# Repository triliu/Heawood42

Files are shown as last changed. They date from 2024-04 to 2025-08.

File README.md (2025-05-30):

# Heawood42

The Heawood42 is a diodeless 42-key ortho-linear split keyboard that uses any pro micro microcontroller. The Heawood42 utilises a new type of circuit design stemming from graph theory and mathematical design theory. All previous diodeless keyboards work using one pin per key, such as the [sweep](https://github.com/davidphilipbarr/Sweep), which uses 17 pins to control 17 keys per side, the [sweeeeep](https://fingerpunch.xyz/product/sweeeeep/), which uses 17 pins to control 17 keys per side, the [cantor](https://github.com/diepala/cantor), which uses 18 pins to control 18 keys per side, and the [piantor](https://github.com/beekeeb/piantor), which uses 21 pins to control 21 keys per side. The first two keyboards can use any pro micro-style board (traditionally, the pro micro-style boards have 18 pins available, but one of these pins is required for communication among the halves). The third and fourth keyboard requires the use of a larger microcontroller, the BlackPills and the Raspberry Pi Pico, respectively. 

The Heawood42 is the first split diodeless keyboard requiring fewer pins than keys. Each side uses 14 pins to control 21 keys. This means that even on a typical pro micro-style board, the Heawood42 may have inter-board communication, addressable RGB lights, and an OLED screen. 

Due to its diodeless-ness, the Heawood42 is ideal in several cases, as it reduces the cost and complexity of making a custom mechanical keyboard.




## Why 'Heawood'?

Typical mechanical keyboards arrange their keys in a grid pattern. In such a grid, there are cycles of four keys. If no diodes were used and three keys of a four-key cycle were pressed, the keyboard would act like all four keys were being pressed. See https://pcbheaven.com/wikipages/How_Key_Matrices_Works/ for an explainer of this phenomenon. By adding a diode to every key, the keyboard becomes "n-key rollover", meaning that the keyboard can theoretically distinguish all combinations of keypresses. In software, however, 6-key rollover is typically used, meaning the software assumes that if more than six keys are being pressed, then keys were pressed on accident. The USB keyboard protocol is limited to a 6-key rollover. For split keyboards, a 6-key rollover on each half is excessive, as typically one finger would only press one key at a time, and even a 5-key rollover is more than is needed. 

In graph theory, it is possible to make graphs that do not contain small cycles. Each graph can be converted into a new type of key matrix, with differing characteristics. The Heawood graph is a graph that is the incidence graph of a projective plane of order 2, and has 14 vertices, 21 edges, and a girth of 6. For more details on this graph, see [House of Graphs](https://houseofgraphs.org/graphs/1154). This graph converts to a key matrix with just a 4-key rollover. However, by designing the board specifically, all problematic 5-key and 6-key sequences may be practically eliminated, yielding the Heawood42. 



This design is powered using any pro micro-style microcontroller.

## Versions
- Regular MX-hotswap version
    - 19.05 x 19.05 spacing
    - MX hot-swap style holes (requires 42 MX hot-swap sockets)
    - Per-key RGB LEDs (optional)
- Choc-hotswap version
    - 18 x 17 spacing
    - Choc hot-swap style holes (requires 42 choc hot-swap sockets)
    - Per-key RGB LEDs (optional)

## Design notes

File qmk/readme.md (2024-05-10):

# Heawood42

Explainer

* Keyboard Maintainer: [Triliu](https://github.com/triliu) 
* Hardware Supported: Heawood42 v1
* Hardware Availability: (coming)

Place these files in .../qmk_firmware/keyboards/triliu/heawood42

To compile in QMK MYSY, run command:

    qmk compile -kb triliu/heawood42/rp2040 -km default
    (coming soon) qmk compile -kb triliu/heawood42/avr -km default

Make example for this keyboard (after setting up your build environment):

    make triliu/heawood42/rp2040:default
    (coming soon) make triliu/heawood42/avr:default

Flashing example for this keyboard:

    make triliu/heawood42/rp2040:default:flash
    (coming soon) make triliu/heawood42/avr:default:flash

First time accessing the bootloader, you might have to hold the boot button and then press the reset button. 
Subsequently, enter bootloader by double-tapping reset button

See the [build environment setup](https://docs.qmk.fm/#/getting_started_build_tools) and the [make instructions](https://docs.qmk.fm/#/getting_started_make_guide) for more information. Brand new to QMK? Start with our [Complete Newbs Guide](https://docs.qmk.fm/#/newbs).

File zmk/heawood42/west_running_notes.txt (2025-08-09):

devcontainer up --workspace-folder "/home/triliu/gits/zmk"
docker ps
docker exec -w /workspaces/zmk -i d5a17f3ab6ca /bin/bash 

west build -p -d build/heawood42/left -b nice_nano_v2 -S studio-rpc-usb-uart -- -DSHIELD=heawood42_left -DCONFIG_ZMK_STUDIO=y
west build -p -d build/heawood42/right -b nice_nano_v2 -S studio-rpc-usb-uart -- -DSHIELD=heawood42_right -DCONFIG_ZMK_STUDIO=y
west build -p -d build/reset -b nice_nano_v2 -- -DSHIELD=settings_reset

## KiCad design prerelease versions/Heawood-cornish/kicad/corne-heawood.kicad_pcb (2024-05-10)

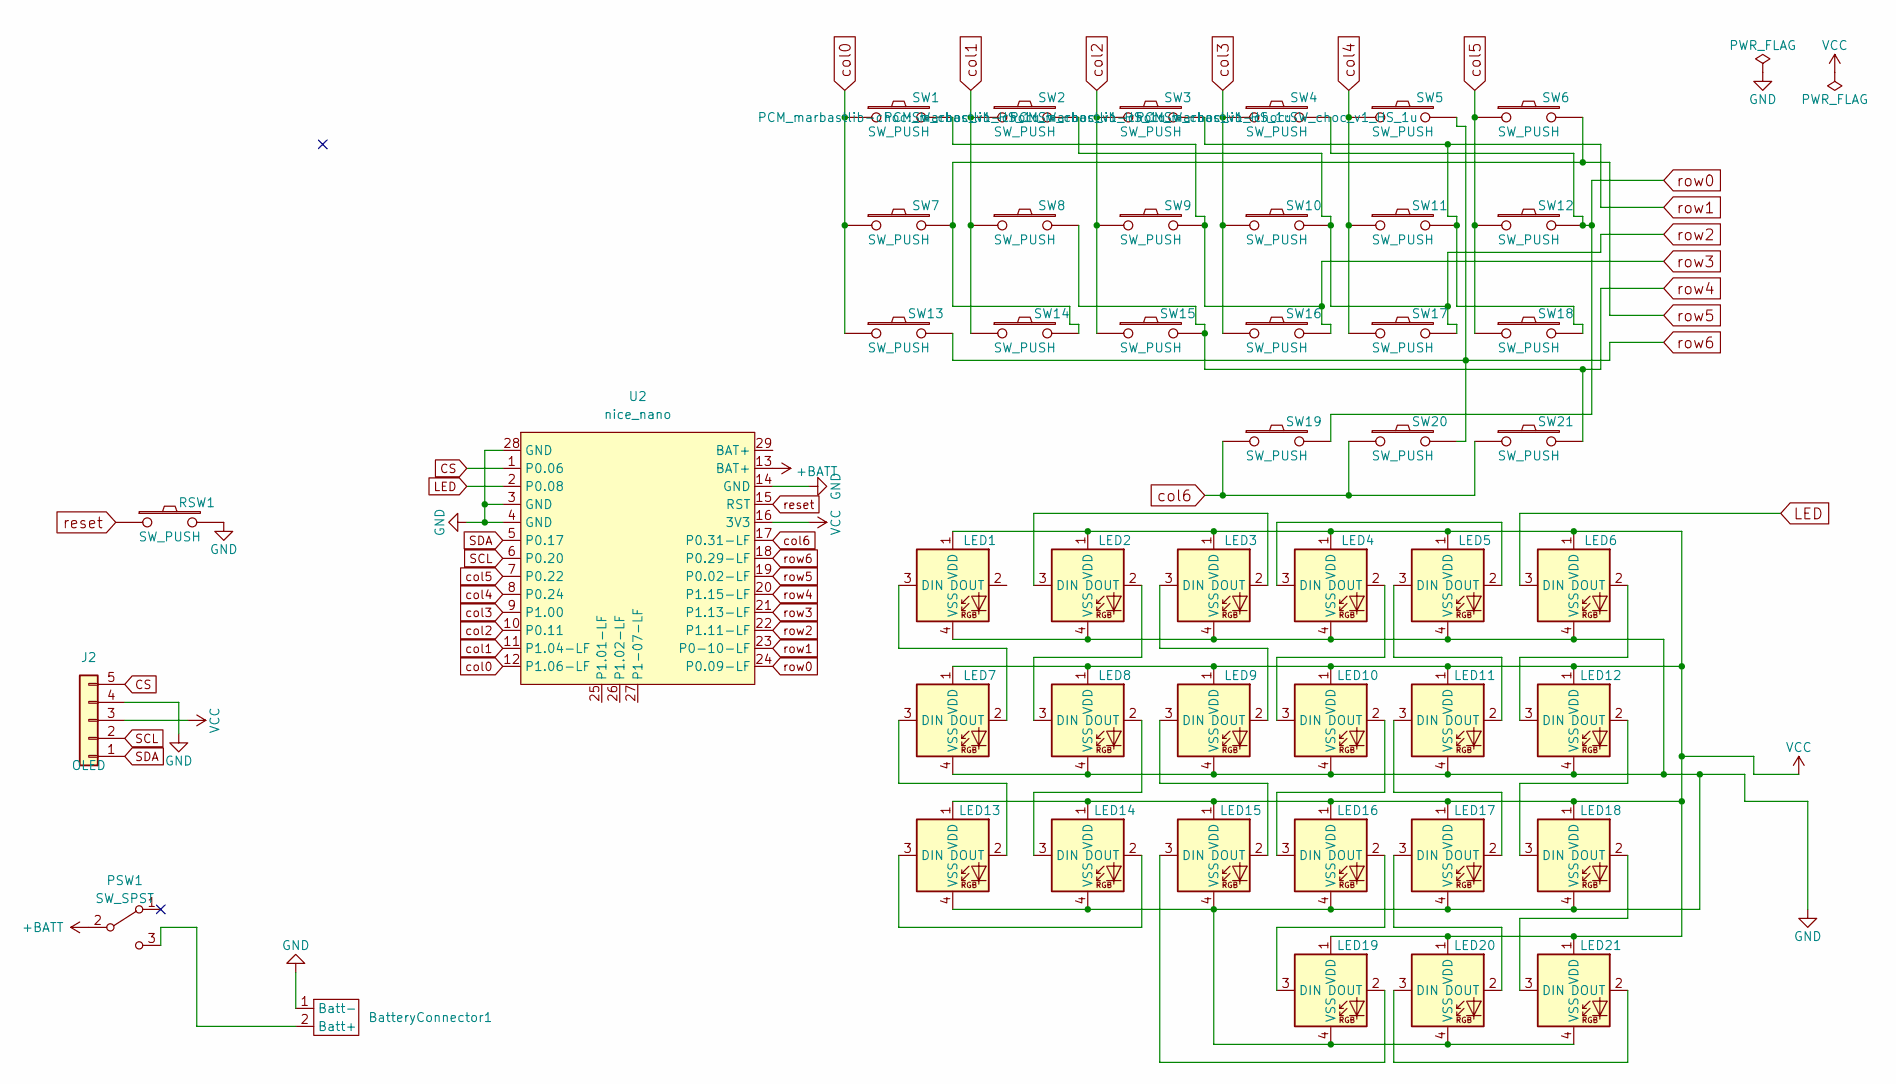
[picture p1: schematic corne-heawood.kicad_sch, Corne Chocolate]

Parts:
BatteryConnector1: 2pad_battery_input
J2: OLED; nice_view_1side
LED1, LED2, LED3, LED4, LED5, LED6, LED7, LED8, LED9, LED10, LED11, LED12, LED13, LED14, LED15, LED16, LED17, LED18, LED19, LED20, LED21: SK6812MINI-E; LED_6028R
PSW1: SW_SPST; SW_SPDT_PCM12
RSW1: SW_PUSH; ResetSW
SW1, SW2, SW3, SW4, SW5, SW6, SW7, SW8, SW9, SW10, SW11, SW12, SW13, SW14, SW15, SW16, SW17, SW18, SW19, SW20: SW_PUSH; SW_choc_v1_HS_1u
SW21: SW_PUSH; SW_choc_v1_HS_1.5u
U2: nice_nano; ProMicro_USBdn

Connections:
+BATT: PSW1.2 (B), U2.13 (BAT+)
CS: U2.1 (P0.06); also elsewhere on the board
GND: BatteryConnector1.1 (Batt-), LED1.4 (VSS), LED2.4 (VSS), LED3.4 (VSS), LED4.4 (VSS), LED5.4 (VSS), LED6.4 (VSS), LED7.4 (VSS), LED8.4 (VSS), LED9.4 (VSS), LED10.4 (VSS), LED11.4 (VSS), LED12.4 (VSS), LED13.4 (VSS), LED14.4 (VSS), LED15.4 (VSS), LED16.4 (VSS), LED17.4 (VSS), LED18.4 (VSS), LED19.4 (VSS), LED20.4 (VSS), LED21.4 (VSS), RSW1.2, U2.3 (GND), U2.4 (GND), U2.14 (GND), U2.28 (GND); also elsewhere on the board
LED: LED6.3 (DIN), U2.2 (P0.08)
unnamed 4: BatteryConnector1.2 (Batt+), PSW1.3 (C); also elsewhere on the board
unnamed: LED1.3 (DIN), LED7.2 (DOUT)
unnamed: LED2.3 (DIN), LED3.2 (DOUT)
unnamed: LED2.2 (DOUT), LED8.3 (DIN)
unnamed: LED3.3 (DIN), LED9.2 (DOUT)
unnamed: LED4.3 (DIN), LED5.2 (DOUT)
unnamed: LED4.2 (DOUT), LED10.3 (DIN)
unnamed: LED10.2 (DOUT), LED16.3 (DIN)
unnamed: LED11.3 (DIN), LED17.2 (DOUT)
unnamed: LED5.3 (DIN), LED11.2 (DOUT)
unnamed: LED6.2 (DOUT), LED12.3 (DIN)
unnamed: LED12.2 (DOUT), LED18.3 (DIN)
unnamed: LED13.3 (DIN), LED14.2 (DOUT)
unnamed: LED7.3 (DIN), LED13.2 (DOUT)
unnamed: LED8.2 (DOUT), LED14.3 (DIN)
unnamed: LED15.3 (DIN), LED19.2 (DOUT)
unnamed: LED9.3 (DIN), LED15.2 (DOUT)
unnamed: LED16.2 (DOUT), LED19.3 (DIN)
unnamed: LED17.3 (DIN), LED20.2 (DOUT)
unnamed: LED18.2 (DOUT), LED21.3 (DIN)
unnamed: LED20.3 (DIN), LED21.2 (DOUT)
SCL: U2.6 (P0.20); also elsewhere on the board
SDA: U2.5 (P0.17); also elsewhere on the board
VCC: LED1.1 (VDD), LED2.1 (VDD), LED3.1 (VDD), LED4.1 (VDD), LED5.1 (VDD), LED6.1 (VDD), LED7.1 (VDD), LED8.1 (VDD), LED9.1 (VDD), LED10.1 (VDD), LED11.1 (VDD), LED12.1 (VDD), LED13.1 (VDD), LED14.1 (VDD), LED15.1 (VDD), LED16.1 (VDD), LED17.1 (VDD), LED18.1 (VDD), LED19.1 (VDD), LED20.1 (VDD), LED21.1 (VDD), U2.16 (3V3); also elsewhere on the board
col0: SW1.1, SW7.1, SW13.1, U2.12 (P1.06-LF)
col1: SW2.1, SW8.1, SW14.1, U2.11 (P1.04-LF)
col2: SW3.1, SW9.1, SW15.1, U2.10 (P0.11)
col3: SW4.1, SW10.1, SW16.1, U2.9 (P1.00)
col4: SW5.1, SW11.1, SW17.1, U2.8 (P0.24)
col5: SW6.1, SW12.1, SW18.1, U2.7 (P0.22)
col6: SW19.1, SW20.1, SW21.1, U2.17 (P0.31-LF)
reset: RSW1.1, U2.15 (RST)
row0: SW4.2, SW12.2, SW19.2, U2.24 (P0.09-LF)
row1: SW3.2, SW11.2, SW18.2, U2.23 (P0-10-LF)
row2: SW2.2, SW10.2, SW17.2, U2.22 (P1.11-LF)
row3: SW1.2, SW9.2, SW16.2, U2.21 (P1.13-LF)
row4: SW8.2, SW15.2, SW21.2, U2.20 (P1.15-LF)
row5: SW6.2, SW7.2, SW14.2, U2.19 (P0.02-LF)
row6: SW5.2, SW13.2, SW20.2, U2.18 (P0.29-LF)

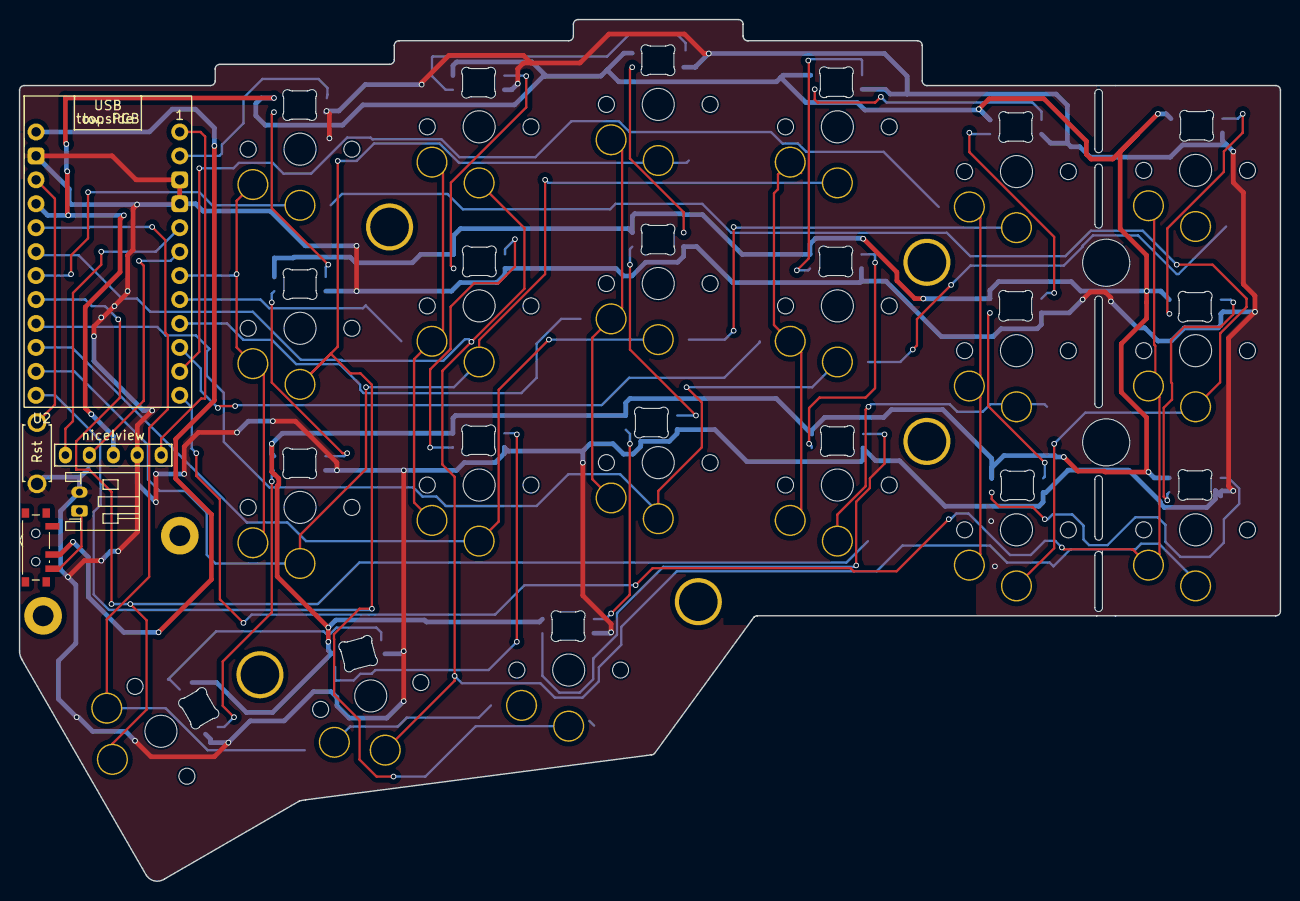
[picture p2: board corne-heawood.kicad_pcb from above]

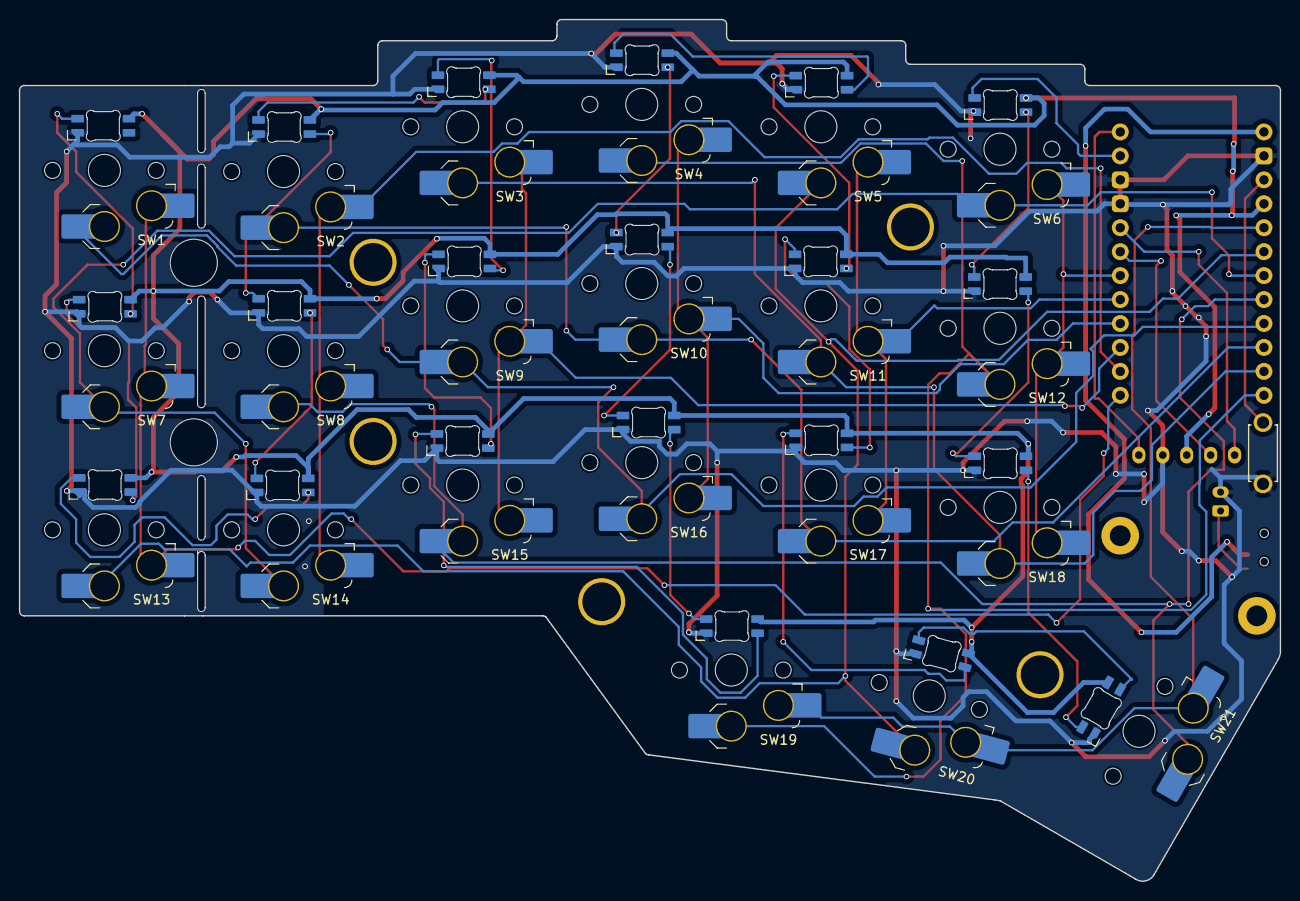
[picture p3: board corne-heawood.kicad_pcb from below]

Board: 2 copper layers, 133.8 x 91.4 mm, 47 parts (43 on the bottom side), 43 nets.

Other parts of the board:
BATJ2: Conn_01x02_Female; JST_PH_S2B-PH-K_1x02_P2.00mm_Horizontal
J1: OLED; nice_view_1side

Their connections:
CS: J1.5; also elsewhere on the board
GND: BATJ2.2, J1.4; also elsewhere on the board
unnamed 4: BATJ2.1; also elsewhere on the board
SCL: J1.2; also elsewhere on the board
SDA: J1.1; also elsewhere on the board
VCC: J1.3; also elsewhere on the board

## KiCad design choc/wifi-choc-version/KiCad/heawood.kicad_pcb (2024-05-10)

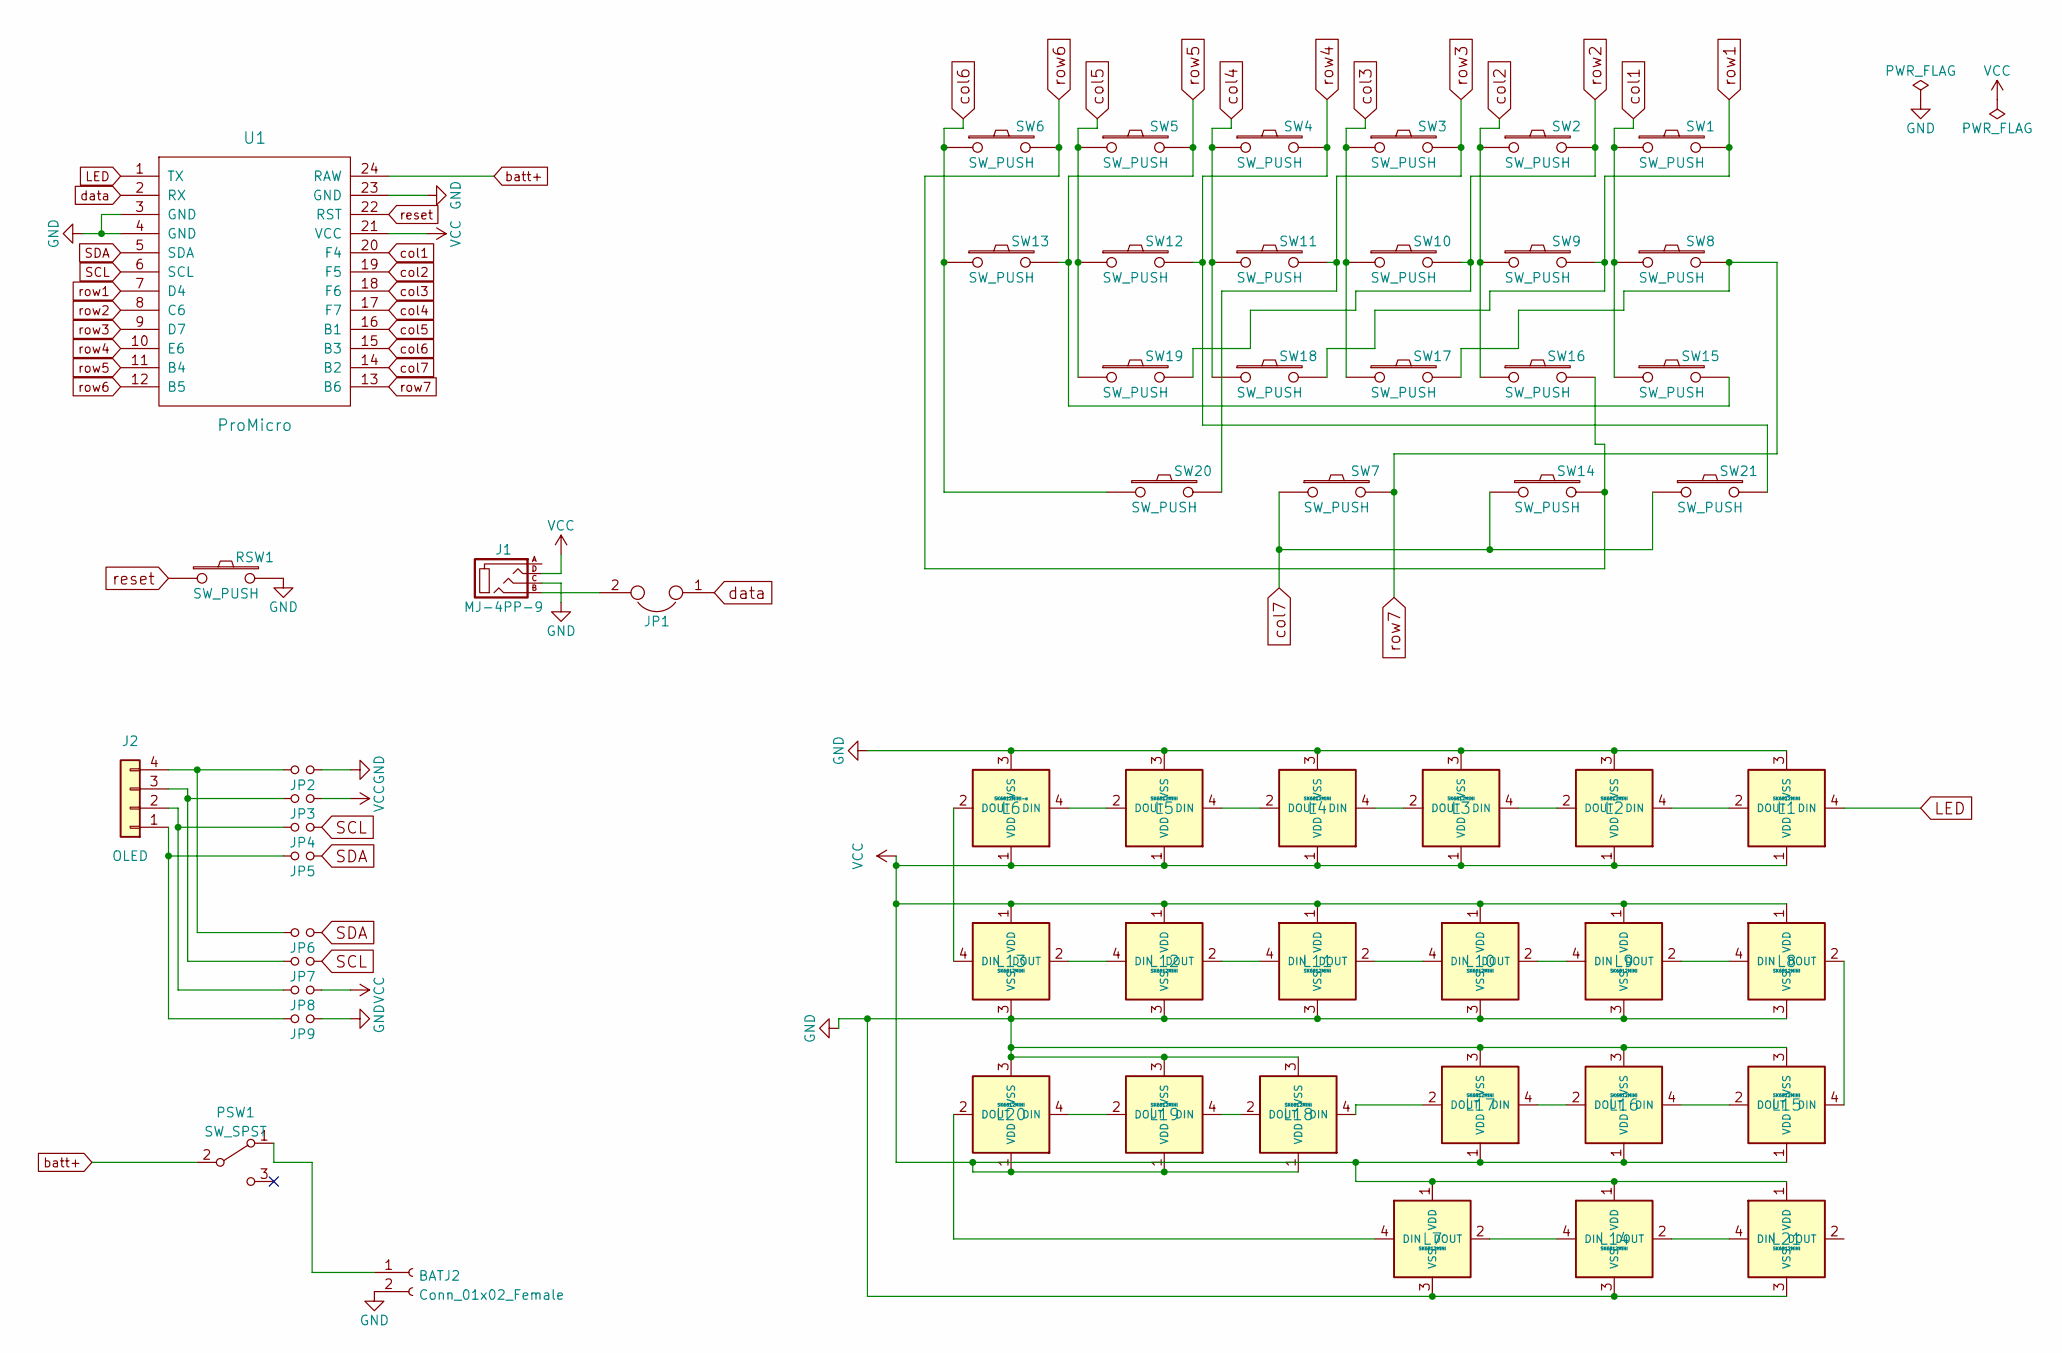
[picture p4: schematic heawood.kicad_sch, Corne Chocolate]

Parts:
BATJ2: Conn_01x02_Female; JST_PH_S2B-PH-K_1x02_P2.00mm_Horizontal
J1: MJ-4PP-9; CON_MJ-4PP-9
J2: OLED
JP1: JPC2
JP2, JP3, JP4, JP5, JP6, JP7, JP8, JP9: Jumper
L1, L2, L3, L4, L5, L7, L8, L9, L10, L11, L12, L13, L14, L15, L16, L17, L18, L19, L20, L21: SK6812MINI; YS-SK6812MINI-E
L6: SK6812MINI-e; YS-SK6812MINI-E
PSW1: SW_SPST; SW_SPDT_PCM12
RSW1: SW_PUSH; ResetSW
SW1, SW2, SW3, SW4, SW5, SW6, SW7, SW8, SW9, SW10, SW11, SW12, SW13, SW15, SW16, SW17, SW18, SW19, SW20, SW21: SW_PUSH; Choc_Hotswap
SW14: SW_PUSH; Choc_Hotswap_1.5u
U1: ProMicro; ProMicro_v2

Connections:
GND: BATJ2.2, J1.C, J2.C, JP2.1, JP9.1, L1.3 (VSS), L2.3 (VSS), L3.3 (VSS), L4.3 (VSS), L5.3 (VSS), L6.3 (VSS), L7.3 (VSS), L8.3 (VSS), L9.3 (VSS), L10.3 (VSS), L11.3 (VSS), L12.3 (VSS), L13.3 (VSS), L14.3 (VSS), L15.3 (VSS), L16.3 (VSS), L17.3 (VSS), L18.3 (VSS), L19.3 (VSS), L20.3 (VSS), L21.3 (VSS), RSW1.2, U1.3 (GND), U1.4 (GND), U1.23 (GND); also elsewhere on the board
LED: L1.4 (DIN), U1.1 (TX); also elsewhere on the board
unnamed: BATJ2.1, PSW1.1 (A)
unnamed: J2.1, JP5.2, JP9.2
unnamed: J2.2, JP4.2, JP8.2
unnamed: J2.3, JP3.2, JP7.2
unnamed: J2.4, JP2.2, JP6.2
unnamed: L1.2 (DOUT), L2.4 (DIN)
unnamed: L2.2 (DOUT), L3.4 (DIN)
unnamed: L3.2 (DOUT), L4.4 (DIN)
unnamed: L4.2 (DOUT), L5.4 (DIN)
unnamed: L5.2 (DOUT), L6.4 (DIN)
unnamed: L8.4 (DIN), L9.2 (DOUT)
unnamed: L10.4 (DIN), L11.2 (DOUT)
unnamed: L9.4 (DIN), L10.2 (DOUT)
unnamed: L11.4 (DIN), L12.2 (DOUT)
unnamed: L12.4 (DIN), L13.2 (DOUT)
unnamed: L6.2 (DOUT), L13.4 (DIN)
unnamed: L7.2 (DOUT), L14.4 (DIN)
unnamed: L14.2 (DOUT), L21.4 (DIN)
unnamed: L8.2 (DOUT), L15.4 (DIN)
unnamed: L15.2 (DOUT), L16.4 (DIN)
unnamed: L16.2 (DOUT), L17.4 (DIN)
unnamed: L17.2 (DOUT), L18.4 (DIN)
unnamed: L18.2 (DOUT), L19.4 (DIN)
unnamed: L19.2 (DOUT), L20.4 (DIN)
unnamed: L7.4 (DIN), L20.2 (DOUT)
unnamed 27: J1.A; also elsewhere on the board
unnamed 28: J1.B, JP1.2; also elsewhere on the board
unnamed: PSW1.2 (B), U1.24 (RAW)
SCL: JP4.1, JP7.1, U1.6 (SCL); also elsewhere on the board
SDA: JP5.1, JP6.1, U1.5 (SDA); also elsewhere on the board
VCC: J1.D, JP3.1, JP8.1, L1.1 (VDD), L2.1 (VDD), L3.1 (VDD), L4.1 (VDD), L5.1 (VDD), L6.1 (VDD), L7.1 (VDD), L8.1 (VDD), L9.1 (VDD), L10.1 (VDD), L11.1 (VDD), L12.1 (VDD), L13.1 (VDD), L14.1 (VDD), L15.1 (VDD), L16.1 (VDD), L17.1 (VDD), L18.1 (VDD), L19.1 (VDD), L20.1 (VDD), L21.1 (VDD), U1.21 (VCC); also elsewhere on the board
col1: SW1.1, SW8.1, SW15.1, U1.20 (F4)
col2: SW2.1, SW9.1, SW16.1, U1.19 (F5)
col3: SW3.1, SW10.1, SW17.1, U1.18 (F6)
col4: SW4.1, SW11.1, SW18.1, U1.17 (F7)
col5: SW5.1, SW12.1, SW19.1, U1.16 (B1)
col6: SW6.1, SW13.1, SW20.1, U1.15 (B3)
col7: SW7.1, SW14.1, SW21.1, U1.14 (B2)
data: JP1.1, U1.2 (RX)
reset: RSW1.1, U1.22 (RST)
row1: SW1.2, SW9.2, SW18.2, U1.7 (D4)
row2: SW2.2, SW10.2, SW19.2, U1.8 (C6)
row3: SW3.2, SW11.2, SW20.2, U1.9 (D7)
row4: SW4.2, SW12.2, SW21.2, U1.10 (E6)
row5: SW5.2, SW13.2, SW15.2, U1.11 (B4)
row6: SW6.2, SW14.2, SW16.2, U1.12 (B5)
row7: SW7.2, SW8.2, SW17.2, U1.13 (B6)

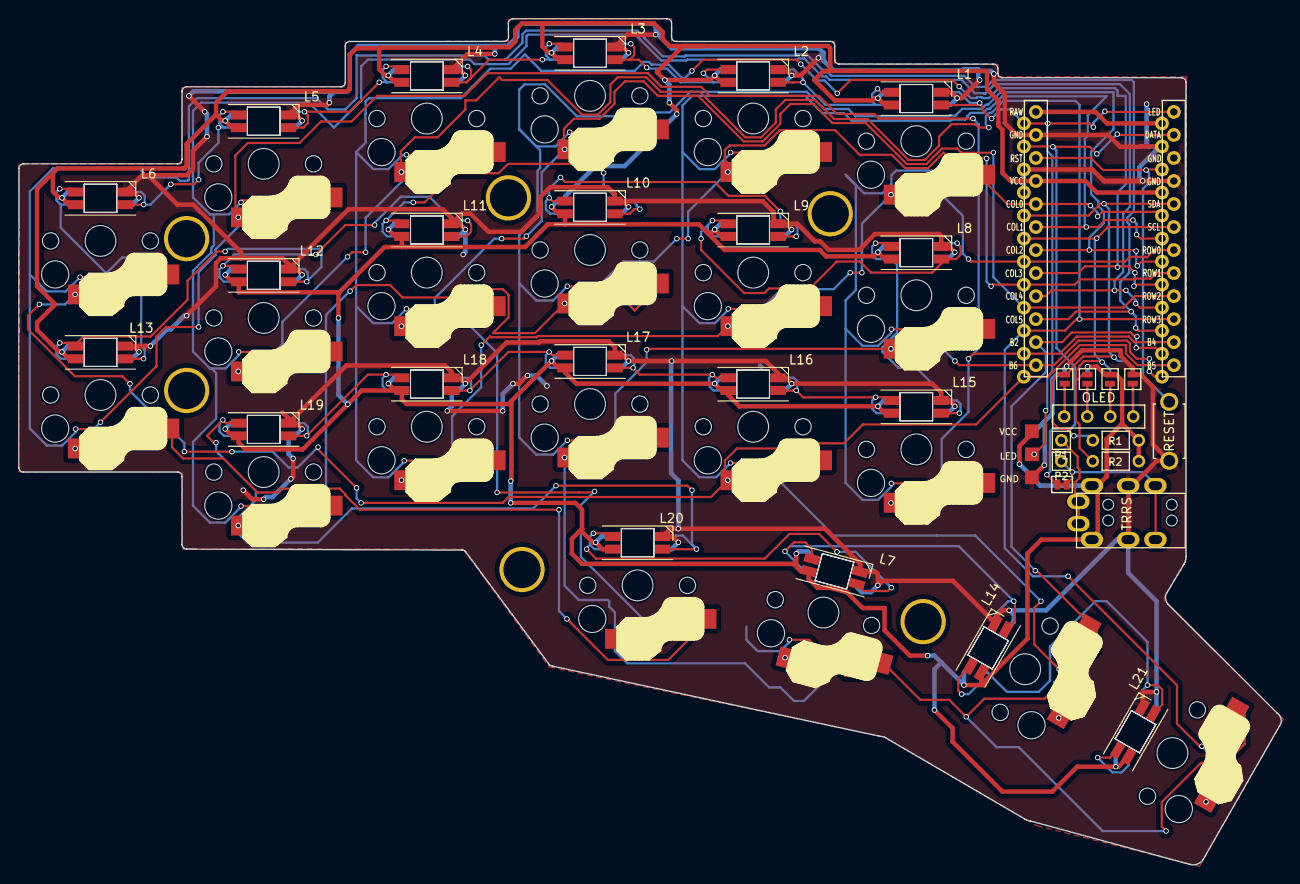
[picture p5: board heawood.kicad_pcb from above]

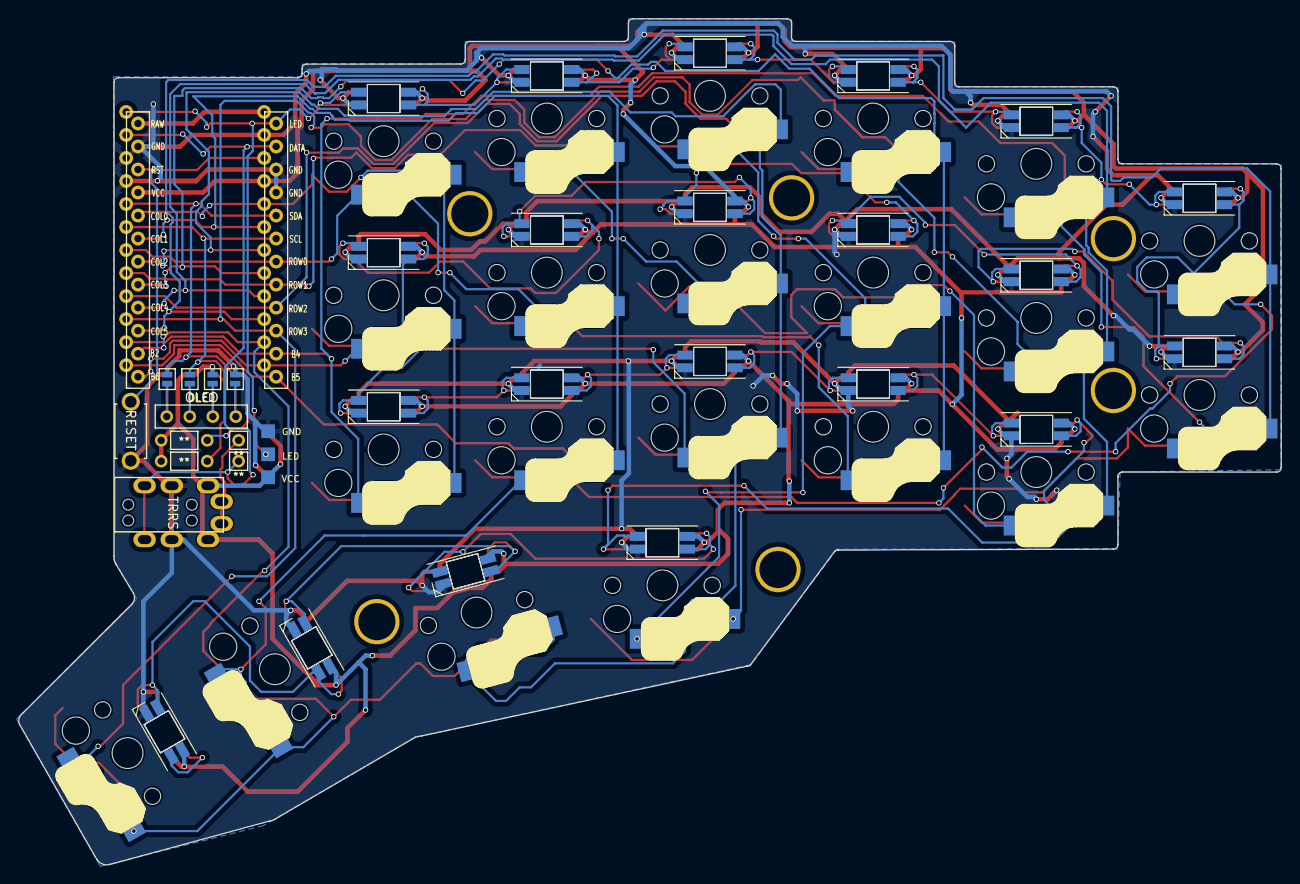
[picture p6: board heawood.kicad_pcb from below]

Board: 2 copper layers, 139.3 x 93.3 mm, 60 parts (4 on the bottom side), 47 nets.

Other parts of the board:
J3: LED; StripLED_rev
P1, P2: i2c-pin; 1pin_conn
R1, R2: R

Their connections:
GND: J3.1; also elsewhere on the board
LED: J3.2; also elsewhere on the board
unnamed 27: P1.1; also elsewhere on the board
unnamed 28: P2.1; also elsewhere on the board
SCL: R2.2; also elsewhere on the board
SDA: R1.2; also elsewhere on the board
VCC: J3.3, R1.1, R2.1; also elsewhere on the board

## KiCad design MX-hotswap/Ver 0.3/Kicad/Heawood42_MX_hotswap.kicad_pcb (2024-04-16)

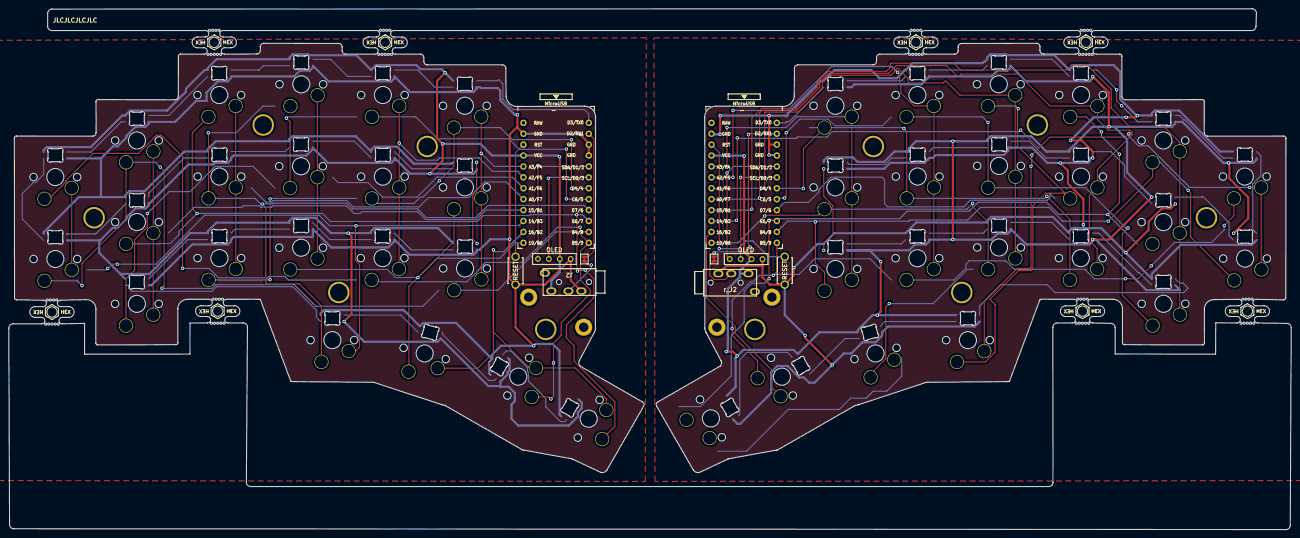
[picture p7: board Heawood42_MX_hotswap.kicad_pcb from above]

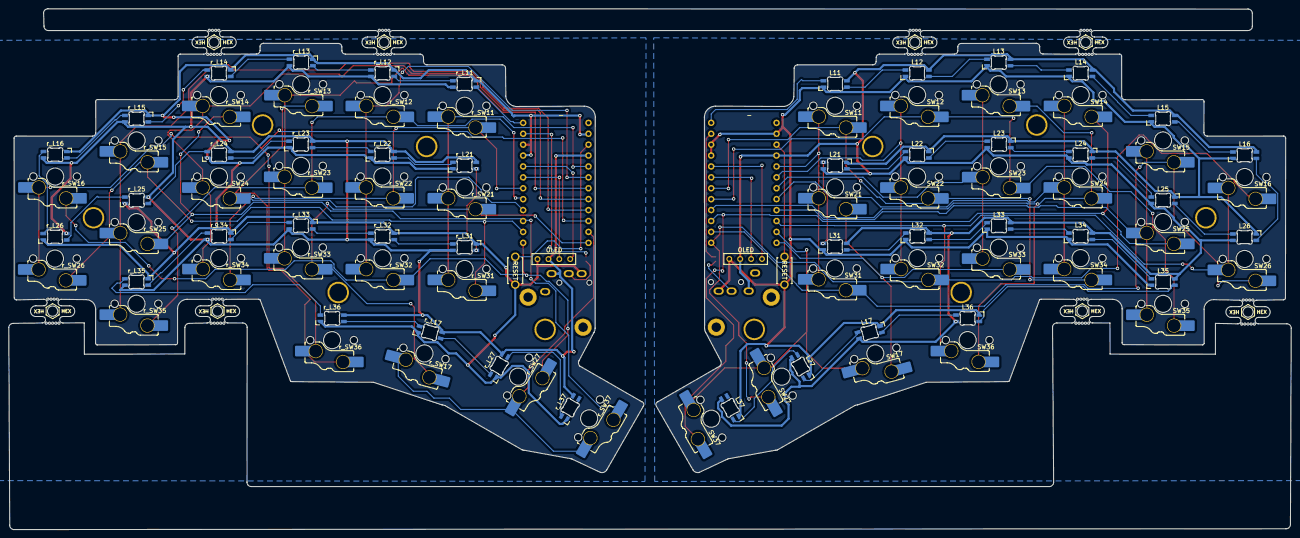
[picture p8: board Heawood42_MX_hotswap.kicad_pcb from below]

Board: 2 copper layers, 298.7 x 121.3 mm, 102 parts (85 on the bottom side), 82 nets.

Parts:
J1: OLED
J2: MJ-4PP-9; CON_MJ-4PP-9
JP1: JPC2
L11, L12, L13, L14, L15, L31, L32, L33, L34, L35: SK6812MINI; LED_MX_6812miniE_rev
L16: SK6812MINI-e; LED_MX_6812miniE_rev
L17, L21, L22, L23, L24, L25, L26, L27, L36, L37: SK6812MINI; LED_MX_6812miniE
MB5, MB5#2, MB5#3, MB5#4, MB5#5, MB5#6, MB5#7, MB5#8: 5.5mm; mousebites_5p5mm_easysnap
RSW1: SW_PUSH; ResetSW
SW11, SW12, SW13, SW14, SW15, SW16, SW17, SW21, SW22, SW23, SW24, SW25, SW26, SW31, SW32, SW33, SW34, SW35, SW36, SW37: SW_PUSH; SW_MX_HS_KS-2P02B01-01_1u
SW27: SW_PUSH; SW_MX_HS_KS-2P02B01-01_1.5u
U1: ProMicro; ProMicro_v3.5
r_J1: r_OLED; OLED
r_J2: MJ-4PP-9; CON_MJ-4PP-9
r_JP1: JPC2
r_L11: SK6812MINI-e; LED_MX_6812miniE
r_L12, r_L13, r_L14, r_L15, r_L16, r_L31, r_L32, r_L33, r_L34, r_L35: SK6812MINI; LED_MX_6812miniE
r_L17, r_L21, r_L22, r_L23, r_L24, r_L25, r_L26, r_L27, r_L36, r_L37: SK6812MINI; LED_MX_6812miniE_rev
r_RSW1: SW_PUSH; ResetSW
r_SW11, r_SW12, r_SW13, r_SW14, r_SW15, r_SW16, r_SW17, r_SW21, r_SW22, r_SW23, r_SW24, r_SW25, r_SW26, r_SW31, r_SW32, r_SW33, r_SW34, r_SW35, r_SW36, r_SW37: SW_PUSH; SW_MX_HS_KS-2P02B01-01_1u
r_SW27: SW_PUSH; SW_MX_HS_KS-2P02B01-01_1.5u
r_U1: ProMicro; ProMicro_v3.5

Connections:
GND: J1.4, J2.S, L11.3 (VSS), L12.3 (VSS), L13.3 (VSS), L14.3 (VSS), L15.3 (VSS), L16.3 (VSS), L17.3 (VSS), L21.3 (VSS), L22.3 (VSS), L23.3 (VSS), L24.3 (VSS), L25.3 (VSS), L26.3 (VSS), L27.3 (VSS), L31.3 (VSS), L32.3 (VSS), L33.3 (VSS), L34.3 (VSS), L35.3 (VSS), L36.3 (VSS), L37.3 (VSS), RSW1.2, U1.3 (GND), U1.4 (GND), U1.23 (GND), r_J1.4, r_J2.1, r_L11.3 (VSS), r_L12.3 (VSS), r_L13.3 (VSS), r_L14.3 (VSS), r_L15.3 (VSS), r_L16.3 (VSS), r_L17.3 (VSS), r_L21.3 (VSS), r_L22.3 (VSS), r_L23.3 (VSS), r_L24.3 (VSS), r_L25.3 (VSS), r_L26.3 (VSS), r_L27.3 (VSS), r_L31.3 (VSS), r_L32.3 (VSS), r_L33.3 (VSS), r_L34.3 (VSS), r_L35.3 (VSS), r_L36.3 (VSS), r_L37.3 (VSS), r_RSW1.2, r_U1.3 (GND), r_U1.4 (GND), r_U1.23 (GND)
LED: L11.4 (DIN), U1.1 (TX)
unnamed: J2.R2, JP1.2
unnamed: L11.2 (DOUT), L12.4 (DIN)
unnamed: L12.2 (DOUT), L13.4 (DIN)
unnamed: L13.2 (DOUT), L14.4 (DIN)
unnamed: L14.2 (DOUT), L15.4 (DIN)
unnamed: L15.2 (DOUT), L16.4 (DIN)
unnamed: L16.2 (DOUT), L26.4 (DIN)
unnamed: L17.4 (DIN), L36.2 (DOUT)
unnamed: L17.2 (DOUT), L27.4 (DIN)
unnamed: L21.4 (DIN), L22.2 (DOUT)
unnamed: L21.2 (DOUT), L31.4 (DIN)
unnamed: L22.4 (DIN), L23.2 (DOUT)
unnamed: L23.4 (DIN), L24.2 (DOUT)
unnamed: L24.4 (DIN), L25.2 (DOUT)
unnamed: L25.4 (DIN), L26.2 (DOUT)
unnamed: L27.2 (DOUT), L37.4 (DIN)
unnamed: L31.2 (DOUT), L32.4 (DIN)
unnamed: L32.2 (DOUT), L33.4 (DIN)
unnamed: L33.2 (DOUT), L34.4 (DIN)
unnamed: L34.2 (DOUT), L35.4 (DIN)
unnamed: L35.2 (DOUT), L36.4 (DIN)
unnamed: r_J2.2, r_JP1.2
unnamed: r_L11.2 (DOUT), r_L12.4 (DIN)
unnamed: r_L12.2 (DOUT), r_L13.4 (DIN)
unnamed: r_L13.2 (DOUT), r_L14.4 (DIN)
unnamed: r_L14.2 (DOUT), r_L15.4 (DIN)
unnamed: r_L15.2 (DOUT), r_L16.4 (DIN)
unnamed: r_L16.2 (DOUT), r_L26.4 (DIN)
unnamed: r_L17.4 (DIN), r_L36.2 (DOUT)
unnamed: r_L17.2 (DOUT), r_L27.4 (DIN)
unnamed: r_L21.4 (DIN), r_L22.2 (DOUT)
unnamed: r_L21.2 (DOUT), r_L31.4 (DIN)
unnamed: r_L22.4 (DIN), r_L23.2 (DOUT)
unnamed: r_L23.4 (DIN), r_L24.2 (DOUT)
unnamed: r_L24.4 (DIN), r_L25.2 (DOUT)
unnamed: r_L25.4 (DIN), r_L26.2 (DOUT)
unnamed: r_L27.2 (DOUT), r_L37.4 (DIN)
unnamed: r_L31.2 (DOUT), r_L32.4 (DIN)
unnamed: r_L32.2 (DOUT), r_L33.4 (DIN)
unnamed: r_L33.2 (DOUT), r_L34.4 (DIN)
unnamed: r_L34.2 (DOUT), r_L35.4 (DIN)
unnamed: r_L35.2 (DOUT), r_L36.4 (DIN)
SCL: J1.2, U1.6 (SCL)
SDA: J1.1, U1.5 (SDA)
VCC: J1.3, J2.1, L11.1 (VDD), L12.1 (VDD), L13.1 (VDD), L14.1 (VDD), L15.1 (VDD), L16.1 (VDD), L17.1 (VDD), L21.1 (VDD), L22.1 (VDD), L23.1 (VDD), L24.1 (VDD), L25.1 (VDD), L26.1 (VDD), L27.1 (VDD), L31.1 (VDD), L32.1 (VDD), L33.1 (VDD), L34.1 (VDD), L35.1 (VDD), L36.1 (VDD), L37.1 (VDD), U1.21 (VCC), r_J1.3, r_J2.3, r_L11.1 (VDD), r_L12.1 (VDD), r_L13.1 (VDD), r_L14.1 (VDD), r_L15.1 (VDD), r_L16.1 (VDD), r_L17.1 (VDD), r_L21.1 (VDD), r_L22.1 (VDD), r_L23.1 (VDD), r_L24.1 (VDD), r_L25.1 (VDD), r_L26.1 (VDD), r_L27.1 (VDD), r_L31.1 (VDD), r_L32.1 (VDD), r_L33.1 (VDD), r_L34.1 (VDD), r_L35.1 (VDD), r_L36.1 (VDD), r_L37.1 (VDD), r_U1.21 (VCC)
col1: SW11.1, SW21.1, SW31.1, U1.20 (F4)
col2: SW12.1, SW22.1, SW32.1, U1.19 (F5)
col3: SW13.1, SW23.1, SW33.1, U1.18 (F6)
col4: SW14.1, SW24.1, SW34.1, U1.17 (F7)
col5: SW15.1, SW25.1, SW35.1, U1.16 (B1)
col6: SW16.1, SW26.1, SW36.1, U1.15 (B3)
col7: SW17.1, SW27.1, SW37.1, U1.14 (B2)
data: JP1.1, U1.2 (RX)
r_LED: r_L11.4 (DIN), r_U1.1 (TX)
r_SCL: r_J1.2, r_U1.6 (SCL)
r_SDA: r_J1.1, r_U1.5 (SDA)
r_col1: r_SW11.1, r_SW21.1, r_SW31.1, r_U1.20 (F4)
r_col2: r_SW12.1, r_SW22.1, r_SW32.1, r_U1.19 (F5)
r_col3: r_SW13.1, r_SW23.1, r_SW33.1, r_U1.18 (F6)
r_col4: r_SW14.1, r_SW24.1, r_SW34.1, r_U1.17 (F7)
r_col5: r_SW15.1, r_SW25.1, r_SW35.1, r_U1.16 (B1)
r_col6: r_SW16.1, r_SW26.1, r_SW36.1, r_U1.15 (B3)
r_col7: r_SW17.1, r_SW27.1, r_SW37.1, r_U1.14 (B2)
r_data: r_JP1.1, r_U1.2 (RX)
r_reset: r_RSW1.1, r_U1.22 (RST)
r_row1: r_SW11.2, r_SW22.2, r_SW34.2, r_U1.7 (D4)
r_row2: r_SW12.2, r_SW23.2, r_SW35.2, r_U1.8 (C6)
r_row3: r_SW13.2, r_SW24.2, r_SW36.2, r_U1.9 (D7)
r_row4: r_SW14.2, r_SW25.2, r_SW37.2, r_U1.10 (E6)
r_row5: r_SW15.2, r_SW26.2, r_SW31.2, r_U1.11 (B4)
r_row6: r_SW16.2, r_SW27.2, r_SW32.2, r_U1.12 (B5)
r_row7: r_SW17.2, r_SW21.2, r_SW33.2, r_U1.13 (B6)
reset: RSW1.1, U1.22 (RST)
row1: SW11.2, SW22.2, SW34.2, U1.7 (D4)
row2: SW12.2, SW23.2, SW35.2, U1.8 (C6)
row3: SW13.2, SW24.2, SW36.2, U1.9 (D7)
row4: SW14.2, SW25.2, SW37.2, U1.10 (E6)
row5: SW15.2, SW26.2, SW31.2, U1.11 (B4)
row6: SW16.2, SW27.2, SW32.2, U1.12 (B5)
row7: SW17.2, SW21.2, SW33.2, U1.13 (B6)

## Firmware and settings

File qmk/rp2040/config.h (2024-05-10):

// Copyright 2022 jack (@waffle87)
// SPDX-License-Identifier: GPL-2.0-or-later
#pragma once

#define RP2040_BOOTLOADER_DOUBLE_TAP_RESET
#define RP2040_BOOTLOADER_DOUBLE_TAP_RESET_TIMEOUT 200U

#define SOFT_SERIAL_PIN GP1

#define I2C_DRIVER I2CD1
#define I2C1_SDA_PIN GP2 //GP22
#define I2C1_SCL_PIN GP3 //GP23

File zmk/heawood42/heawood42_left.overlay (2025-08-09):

#include "heawood42.dtsi"

&kscan0 {
    col-gpios
        = <&pro_micro 21 GPIO_OPEN_SOURCE> // col1 in the schematic
        , <&pro_micro 20 GPIO_OPEN_SOURCE> // col2 in the schematic
        , <&pro_micro 19 GPIO_OPEN_SOURCE> // col3 in the schematic
        , <&pro_micro 18 GPIO_OPEN_SOURCE> // col4 in the schematic
        , <&pro_micro 15 GPIO_OPEN_SOURCE> // col5 in the schematic
        , <&pro_micro 14 GPIO_OPEN_SOURCE> // col6 in the schematic
        , <&pro_micro 16 GPIO_OPEN_SOURCE> // col7 in the schematic
        ;
};

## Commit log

2024-03-16 Add pre-release cornish heawood
    [corne-heawood-flip.kicad_pcb, corne-heawood-flip.kicad_sch, corne-heawood.kicad_pcb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]
2024-03-20 Added Gerbers
    [Heawood42.kicad_pcb, Heawood42.kicad_sch]
2024-03-22 MX and MX-hotswap updates
    [Heawood42_MX.kicad_pcb, Heawood42_MX.kicad_sch, Heawood42_MX_hotswap.kicad_pcb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]
2024-04-16 zmk fix. GPIO are now GPIO_OPEN_SOURCE
    [Heawood42_MX.kicad_pcb, Heawood42_MX.kicad_sch, Heawood42_MX_hotswap.kicad_pcb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]
2024-05-10 Add QMK firmware files
    [corne-heawood.kicad_pcb, corne-heawood.kicad_sch, heawood.kicad_pcb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]
